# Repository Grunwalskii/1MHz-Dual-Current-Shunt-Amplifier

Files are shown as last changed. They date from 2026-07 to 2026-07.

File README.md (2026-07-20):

# ⚡ 1MHz Dual-Range Current Shunt Amplifier

High-bandwidth, high-precision dual-range current shunt measurement module. Featuring two independent sensing stages ($50\text{ m}\Omega$ for high-current paths and $500\text{ m}\Omega$ for low-current profiling), this board is engineered for dynamic, high-speed power analysis across a wide range of loads, achieving up to $1\text{ MHz}$ bandwidth performance.

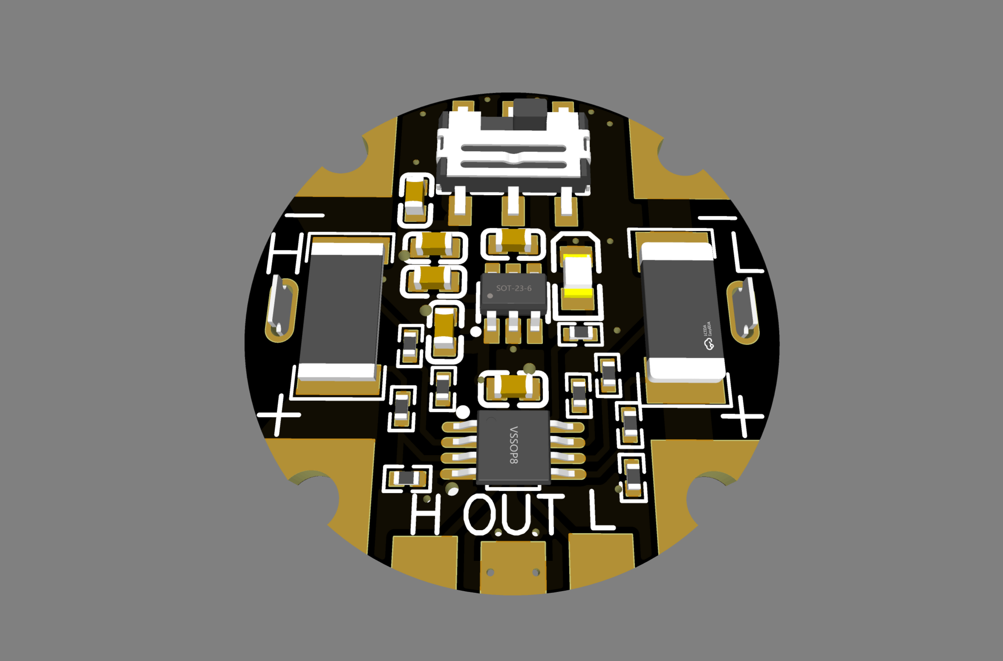
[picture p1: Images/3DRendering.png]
Rendering


## 🛠️ Key Architectural Features

### 1. Dual-Range Precision Sensing
* **High-Current (HC) Stage:** Employs a precision $50\text{ m}\Omega$ inline shunt resistor (`R3`) coupled with an operational amplifier stage providing a stable $20\times$ differential gain ($R_2/R_1 = 20\text{ k}\Omega / 1\text{ k}\Omega$).
* **Low-Current (LC) Stage:** Employs a higher sensitivity $500\text{ m}\Omega$ inline shunt resistor (`R6`) paired with an identical $20\times$ differential gain amplifier configuration ($R_{10}/R_7 = 20\text{ k}\Omega / 1\text{ k}\Omega$).
* **Dedicated Analog Outputs:** Yields independent, buffered analog voltage outputs (`HCOUT` and `LCOUT`) tailored for direct oscilloscope observation or high-speed ADC sampling.

### 2. High-Performance Signal Conditioning
* **Amplifier Core:** Powered by the **OPA2322AIDGKR** (`U1`), a dual, low-noise, low-power, rail-to-rail input/output operational amplifier featuring excellent bandwidth capabilities ($20\text{ MHz}$ GBW product) to effortlessly sustain clean signals up to the target $1\text{ MHz}$ measurement threshold.

### 3. Floating Measurement
* **True Floating Measurement (High-Side & Low-Side Versatility):** Standard mains-powered test equipment or USB power supplies share a common ground with the target system. By powering the OPA2322 via an isolated coin-cell battery (`U4`) and the `HX4002` charge pump, the entire amplifier circuit becomes **fully floating**. This allows you to safely insert the shunts anywhere in the circuit—either on the high-side (before the load) or the low-side (after the load)—without creating dangerous ground loops that ruin measurements or damage equipment.

---

## 🔌 Core Interface Map

### Sensing Terminals
* `HC+` / `HC-`: High-current shunt path inputs ($50\text{ m}\Omega$).
* `LC+` / `LC-`: Low-current shunt path inputs ($500\text{ m}\Omega$).

### Output Test Points
* `HCOUT`: Analog signal output for the High-Current stage.
* `LCOUT`: Analog signal output for the Low-Current stage.

* ## Support

If you enjoy this project and want to support its development, you can buy me a coffee:



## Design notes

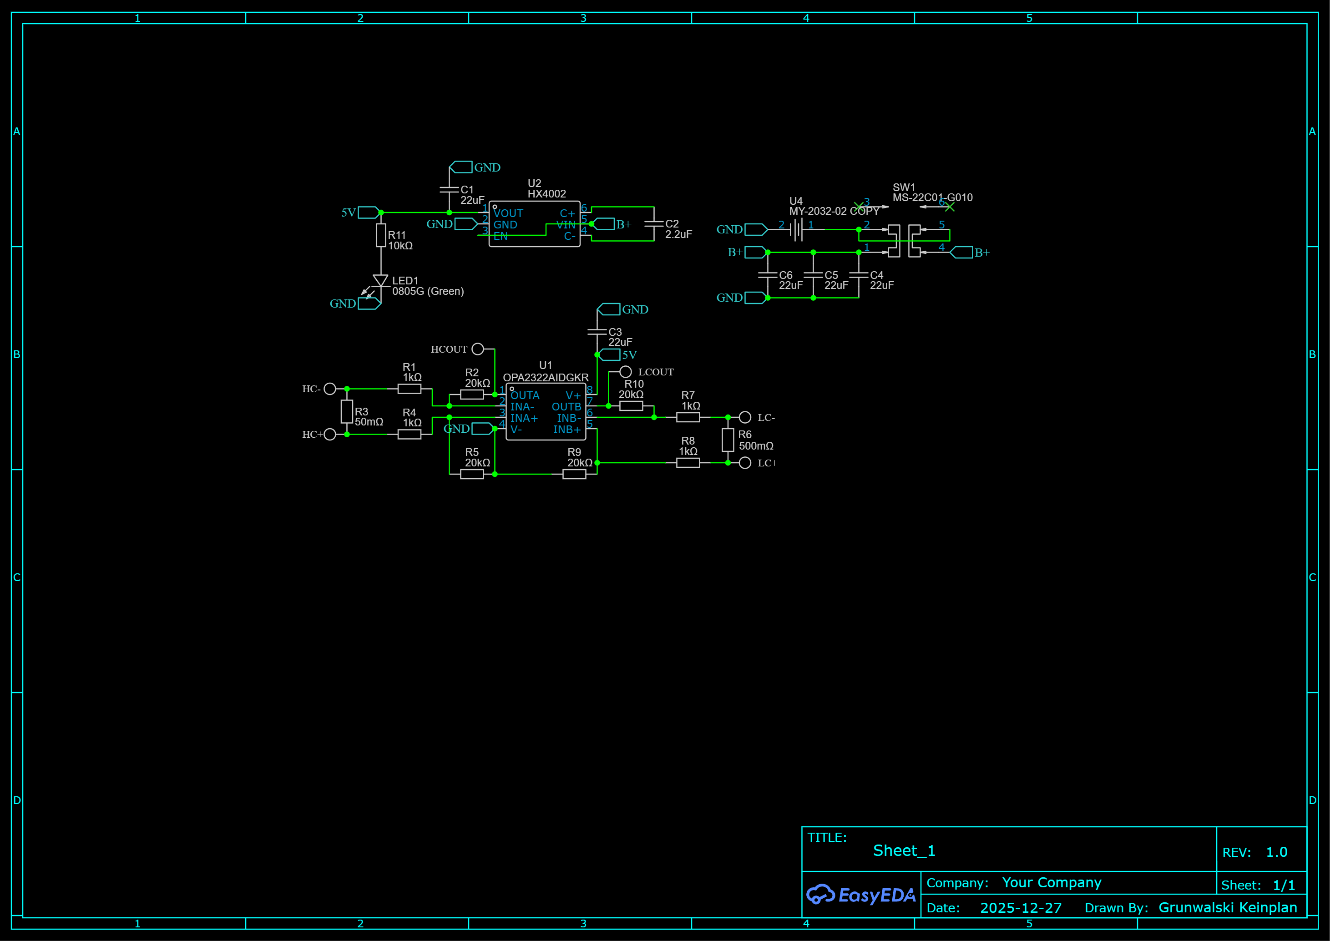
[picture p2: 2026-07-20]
Images/Schematic.png

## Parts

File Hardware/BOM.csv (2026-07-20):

ID | Name | Designator | Footprint | Quantity | Manufacturer Part | Manufacturer | Supplier | Supplier Part | Price
1 | 22uF | C1,C3,C4,C5,C6 | C0603 | 5 | CL10A226MQ8NRNC | SAMSUNG(三星) | LCSC | C59461 | 0.044
2 | 2.2uF | C2 | C0603 | 1 | CL10A225KO8NNNC | SAMSUNG(三星) | LCSC | C23630 | 0.029
3 | Pad | HC+,HC-,HCOUT,LC+,LC-,LCOUT | PAD | 6
4 | 0805G (Green) | LED1 | LED0805-R-RD | 1 | KT-0805G | KENTO | LCSC | C2297 | 0.016
5 | 1kΩ | R1,R4,R7,R8 | R0402 | 4 | RT0402BRD071KL | YAGEO(国巨) | LCSC | C852624 | 0.028
6 | 20kΩ | R2,R5,R9,R10 | R0402 | 4 | RT0402BRD0720KL | YAGEO(国巨) | LCSC | C705630 | 0.03
7 | 50mΩ | R3 | R2512 | 1 | JER2512F2R050 | JIERR(捷而瑞) | LCSC | C49164908 | 0.081
8 | 500mΩ | R6 | RES-SMD_L6.4-W3.2-R2512 | 1 | FRM252WJR500TK | FOJAN(富捷) | LCSC | C7420030 | 0.043
9 | 10kΩ | R11 | R0402 | 1 | 0402WGF1002TCE | UNI-ROYAL(厚声) | LCSC | C25744 | 0.009
10 | MS-22C01-G010 | SW1 | SW-SMD_6P-L7.2-W3.5-P2.50-LS6.0-TL | 1 | MS-22C01-G010 | G-Switch(品赞) | LCSC | C2837066 | 0.133
11 | OPA2322AIDGKR | U1 | VSSOP-8_L3.0-W3.0-P0.65-LS5.0-BL | 1 | OPA2322AIDGKR | TI(德州仪器) | LCSC | C2058180 | 1.059
12 | HX4002 | U2 | SOT-23-6_L2.9-W1.6-P0.95-LS2.8-BR | 1 | HX4002-MFC | HEXIN(禾芯微) | LCSC | C172354 | 0.099
13 | MY-2032-02 COPY | U4 | BATT-TH_MY-2032-02 | 1 | MY-2032-02 | MYOUNG(美阳) | LCSC | C964822 | 0.135
